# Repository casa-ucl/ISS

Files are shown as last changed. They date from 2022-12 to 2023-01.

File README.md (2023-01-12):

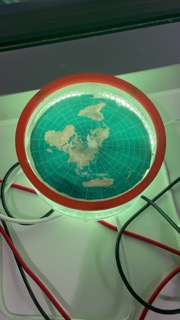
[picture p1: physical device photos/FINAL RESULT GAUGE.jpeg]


# ISS-Tracker-Overview

Welcome to our International Space Station (ISS) Tracking Device project! This project is a physical gauge that displays the position and visibility of the ISS in real-time using a combination of a rotating map, LED lights, and a servo motor. The device was developed by a team of students and is powered by an Arduino NodeMCU board.

This GitHub repository contains all the files and information related to the project, including:

The code for the NodeMCU and the augmented reality app
3D model files for the physical device and the animation created in Blender
Photos and instructions for 3D printing the device
The project report and bibliography
Collaboration folder that contains information on the team members' individual contributions and their roles on the project
To access and use the files, please navigate through the different folders and open the files in the appropriate software.
If you have any questions or feedback, please do not hesitate to contact us. Thank you for visiting our repository and we hope you enjoy our project.

# Introduction

First launched in 1998, The International Space Station (ISS) is the Earth’s biggest artificial satellite and the largest spacecraft ever constructed. It is the world’s only microgravity science lab where researchers conduct experiments across a wide variety of disciplines, often with groundbreaking results (NASA, 2020).  Its unique research environment and level of international cooperation required for its running make the ISS  “the most complex engineering, scientific, collaborative human feat ever managed” (NASA, 2020). Orbiting about 400 kilometers above Earth, it travels 28,000km/h and makes a complete orbits every 90 minutes, or 16 times per day. The ISS reflects sunlight and can be seen with the naked eye as a bright white pinpoint of light in the sky moving at a constant speed (NASA, 2013). Spotting the ISS is a popular hobby, and is regarded as one of the most intriguing and rewarding stargazing activities (Beall, 2023). For that reason, there are many apps and websites dedicated to mapping the live location of the ISS, such as AstroViewer (AstroViewer, 2022), NASA’s Spot the Station (Spot The Station, 2020), and mobile applications GoISSWatch ISS Tracking (GoSoftWorks, 2021), and ISS Finder (Harry Slotwiner, 2022). Following this trend, our team thought it would be fulfilling to create a physical device that tracked the location of this iconic spacecraft.

# Workspace
* 3D printer (Original Prusa i3 MK3S or MK3S+)
* Fusion 360 for 3D modeling
* [Blender for animation](https://www.youtube.com/watch?v=Yl_qDDRlXHo)
* Unity for AR development and Google Pixel 4a as the target platform
* Servo motors, LEDs, and acrylic sheets to construct the physical device
* Arduino IDE and C# for programming

# physical divice component
- Servo motors
- LEDs
- Acrylic sheets
- Arduino NodeMCU
- 360 Lego Geekservo
- Adafruit Neopixel Stick
- WS2812B LED Strip
- Globe map

# For the Arduino code:
- Remeber to change the WiFi credentials to the WiFi you want to connect to.
- When it starts, expect the LED strip (visibility) to turn on white.
- Expect all the LEDs on the NeoPixel board (latitude) to turn on red.
- Expect the servo (longitude) to turn to the 0 degrees location.
- Move the map so that the 0 degrees latitude line is aligned to the led line formed by the latitude LEDs.
- The device will automatically make a request to the API and once it recives a response the lights and servo will then update automatically every 5 seconds to the correct positions.

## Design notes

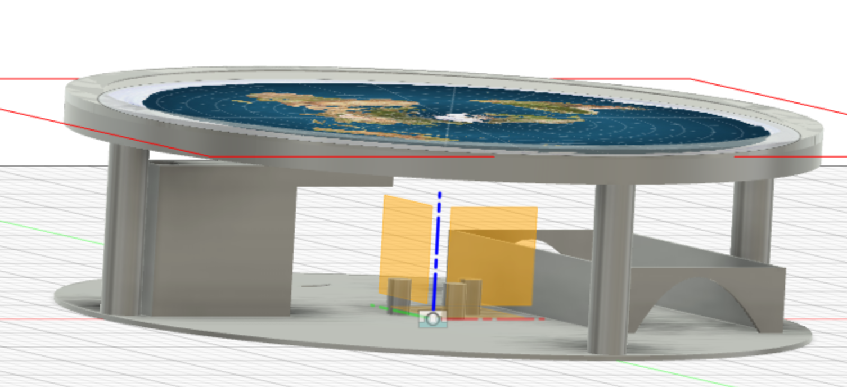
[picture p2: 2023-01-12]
physical device photos/into the gauge fusion 360.png

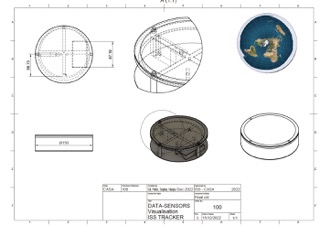
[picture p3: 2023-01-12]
physical device photos/drawing screen shot Small.jpeg

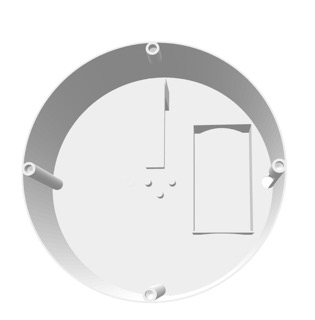
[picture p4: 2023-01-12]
physical device photos/Gaugebase Small.jpeg

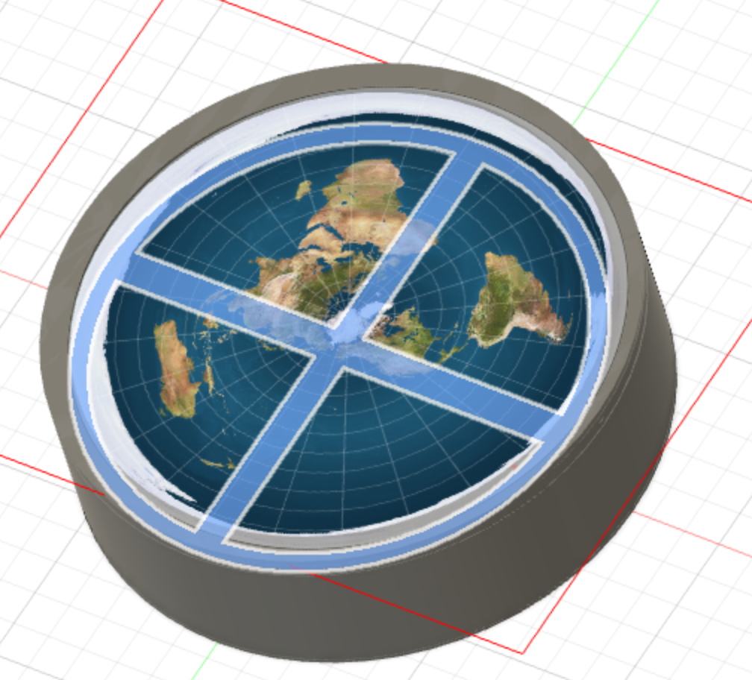
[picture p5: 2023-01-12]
physical device photos/map holder .png

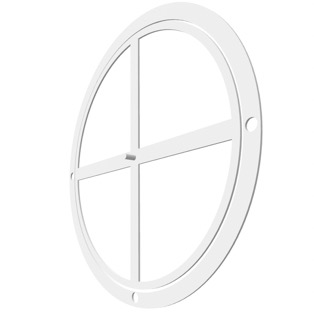
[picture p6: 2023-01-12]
physical device photos/Mapholder(wheel) Small.jpeg

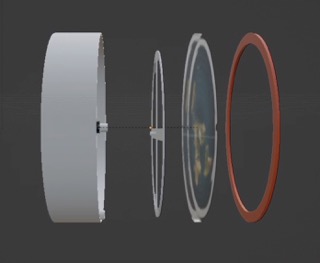
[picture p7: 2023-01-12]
physical device photos/Blender exploded Small.jpeg

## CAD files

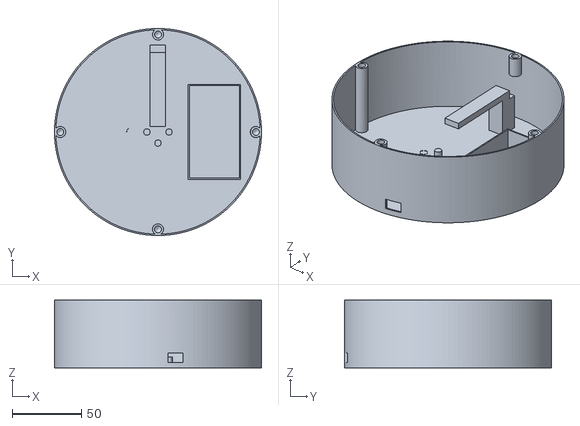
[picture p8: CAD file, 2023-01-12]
ISS Designing (all type of files)/UNity version v1 v7.stl
150.0 x 150.0 x 49.0

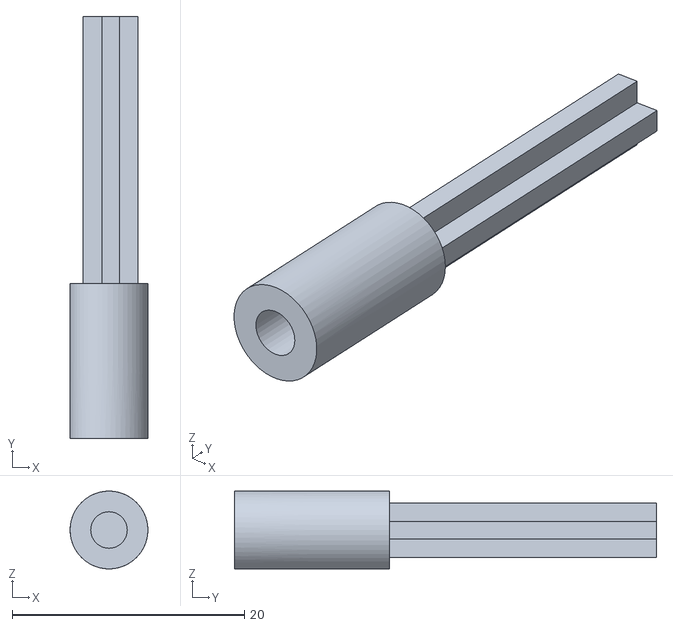
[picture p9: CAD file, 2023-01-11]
ISS Designing (all type of files)/LegoConnector.stl
6.70 x 36.3 x 6.70

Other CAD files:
ISS Designing (all type of files)/UNity version.f3d

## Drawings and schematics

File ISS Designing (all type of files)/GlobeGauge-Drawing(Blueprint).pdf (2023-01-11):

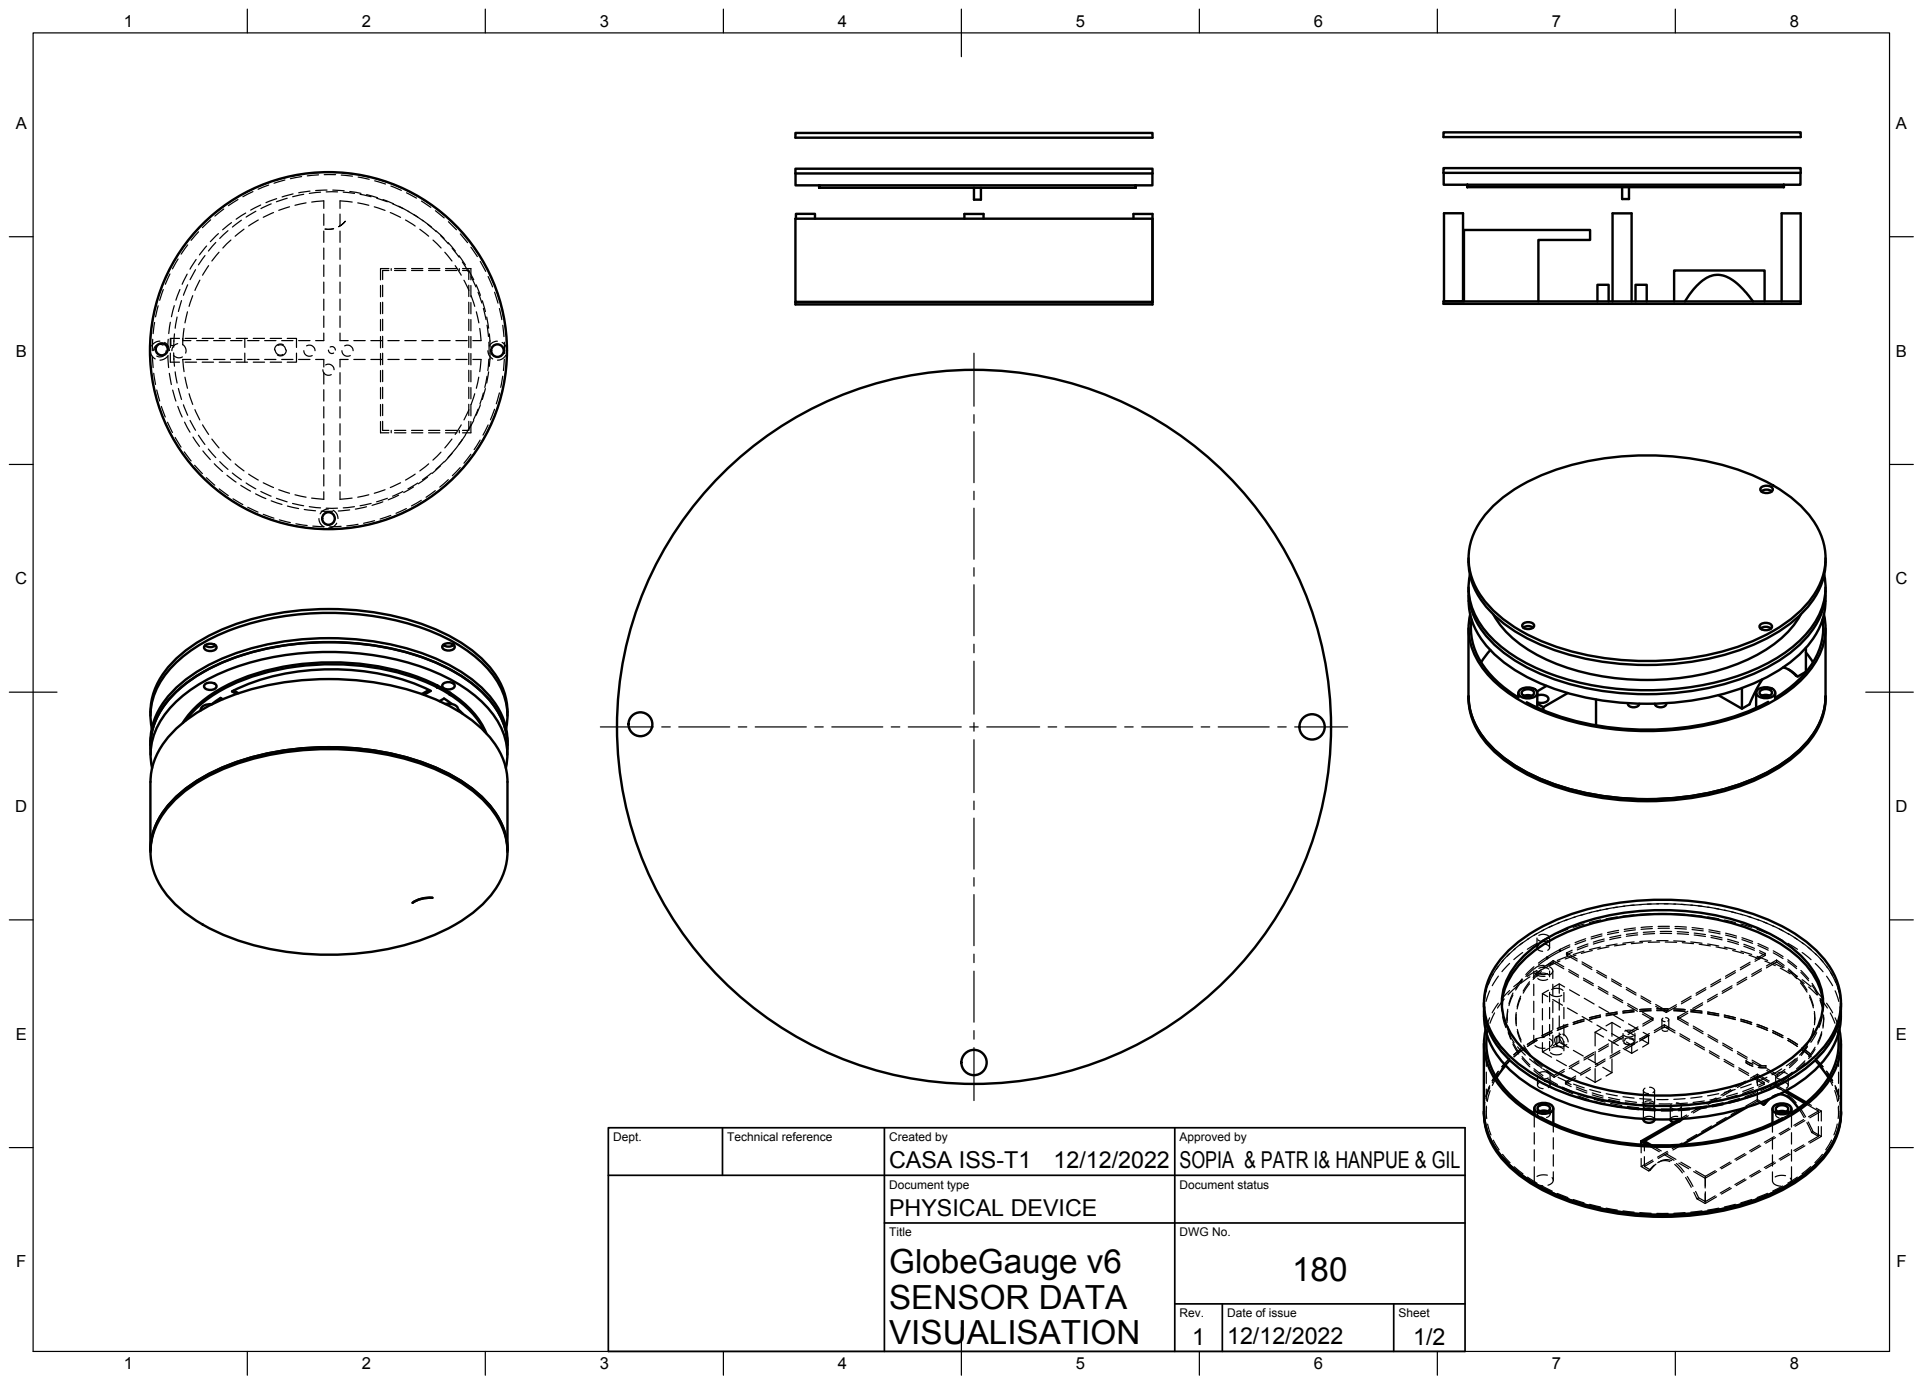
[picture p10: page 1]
Title; DWG No.; Rev.; Date of issue; Sheet; SENSOR DATA; GlobeGauge v6

Dept. | Technical reference | Created by CASA ISS-T1 12/12/2022 | Approved by SOPIA & PATR I& HANPUE & GIL

Document type PHYSICAL DEVICE | Document status

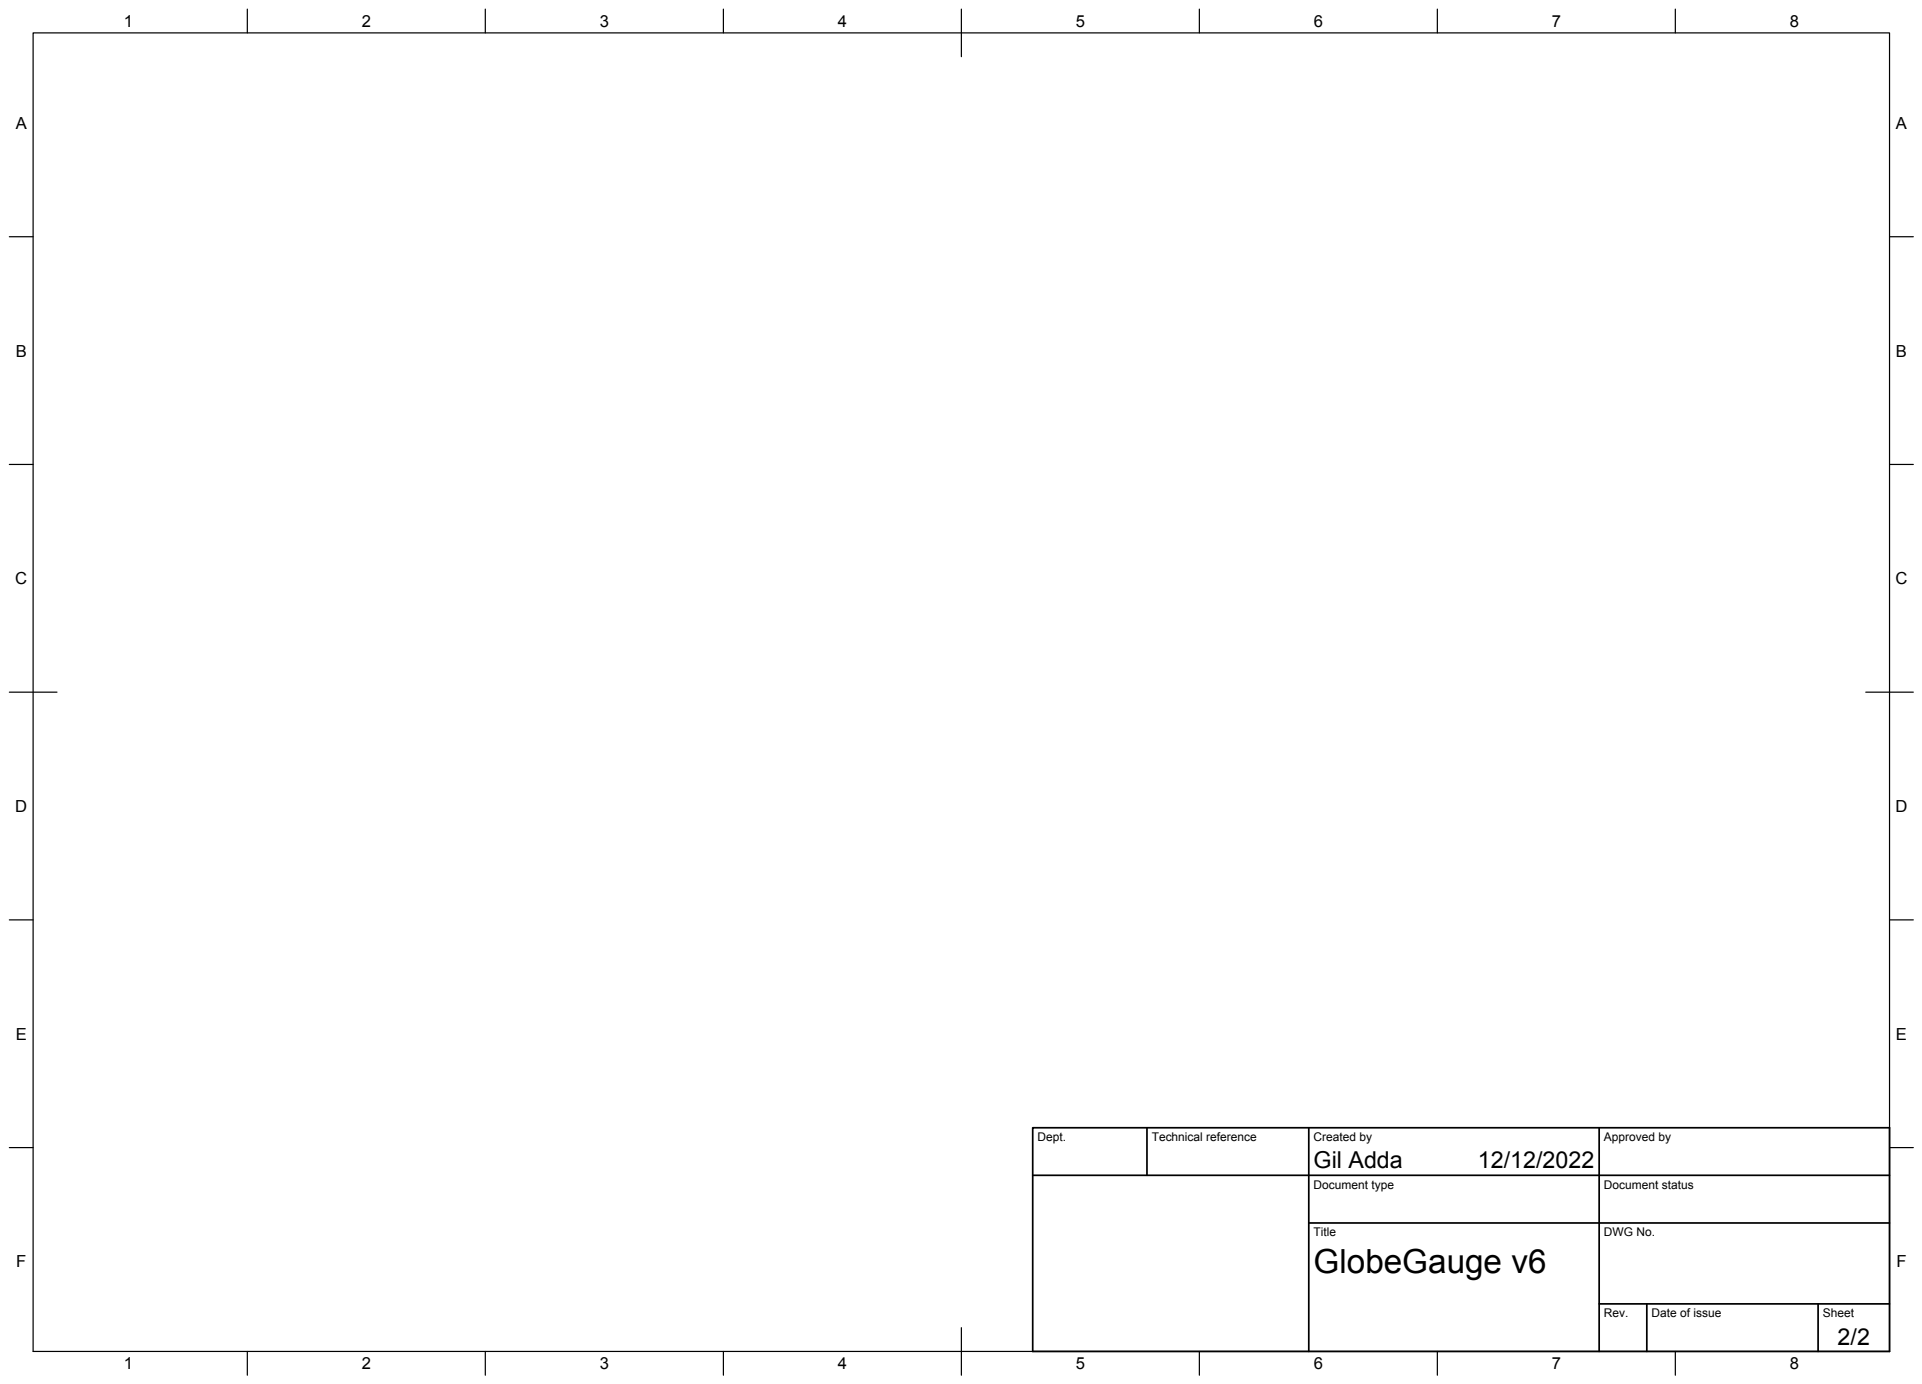
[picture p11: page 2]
Title; DWG No.; Rev.; Date of issue; Sheet; GlobeGauge v6

Dept. | Technical reference | Created by Gil Adda 12/12/2022 | Approved by

Document type | Document status

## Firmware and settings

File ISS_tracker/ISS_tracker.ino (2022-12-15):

/*
 * CASA0019 Group Project - ISS Tracker
 * Group 1 Astronaut - Gil Adda, Patrick Whyte, Sophia Chong, Hanpu Liu
 *
 * Using:
 * HTTPS Secured Client GET Request
 * Copyright (c) 2019, circuits4you.com
 * All rights reserved.
 * https://circuits4you.com 
 */

#include <ESP8266WiFi.h>
#include <WiFiClientSecure.h> 
#include <ESP8266WebServer.h>
#include <ESP8266HTTPClient.h>
#include <ArduinoJson.h>

#include <Servo.h>
#include <Adafruit_NeoPixel.h>

#define LAT_LED_PIN 12 // PIN D6 on NodeMCU
#define LAT_NUM_PIXELS 8

#define VIS_LED_PIN 14 // PIN D5 on NodeMCU
#define VIS_NUM_PIXELS 100

#define LON_SER_PIN 13 // PIN D7 on NodeMCU

/* Set these to your desired credentials. */
const char *ssid = "CE-Hub-Student";  //ENTER YOUR WIFI SETTINGS
const char *password = "casa-ce-gagarin-public-service";

//Web/Server address to read/write from 
const char *host = "api.wheretheiss.at";
const int httpsPort = 443;  //HTTPS= 443 and HTTP = 80

//SHA1 finger print of certificate use web browser to view and copy
const char fingerprint[] PROGMEM = "D5 28 75 E9 DB C8 8C 13 7A 9E 2B 04 B0 09 C3 D8 DE 7B 6E FB";

//API variables
int latitude;
int longitude;
String visibility;

//JSON document
DynamicJsonDocument doc(2048);

// Geekservo (longitude)
Servo servo;

// Initialize NeoPixel 8 Board (latitude)
Adafruit_NeoPixel pixels(LAT_NUM_PIXELS, LAT_LED_PIN);
// Initialize NeoPixel Strip (visibility)
Adafruit_NeoPixel strip(VIS_NUM_PIXELS, VIS_LED_PIN,  NEO_RGB + NEO_KHZ800);

void setup() {
  delay(1000);
  Serial.begin(115200);

  // Servo Code
  servo.attach(LON_SER_PIN);
  servo.write(0);

  // start NeoPixel board LEDs and set them all to be red to initalize
  pixels.begin();
  for (int i = 0; i < LAT_NUM_PIXELS; i++){
    pixels.setPixelColor(i, 200, 0, 0);
    pixels.show();
  }

  // Start Strip LEDs and set them to be white to initalize
  strip.begin();
  for (int i = 0; i < VIS_NUM_PIXELS; i++){
      strip.setPixelColor(i, 200, 200, 200);
      strip.show();
    }

  //start of wifi code TODO: move bloc to own function
  WiFi.mode(WIFI_OFF);        //Prevents reconnection issue (taking too long to connect)
  delay(1000);
  WiFi.mode(WIFI_STA);        //Only Station No AP, This line hides the viewing of ESP as wifi hotspot
  
  WiFi.begin(ssid, password);     //Connect to your WiFi router
  Serial.println("");

  Serial.print("Connecting");
  // Wait for connection
  while (WiFi.status() != WL_CONNECTED) {
    delay(500);
    Serial.print(".");
  }

  //If connection successful show IP address in serial monitor
  Serial.println("");
  Serial.print("Connected to ");
  Serial.println(ssid);
  Serial.print("IP address: ");
  Serial.println(WiFi.localIP());
}

void loop() {
  WiFiClientSecure httpsClient;

  Serial.println(host);

  Serial.printf("Using fingerprint '%s'\n", fingerprint);
  httpsClient.setFingerprint(fingerprint);
  httpsClient.setTimeout(15000); // 15 Seconds
  delay(1000);
  
  Serial.print("HTTPS Connecting");
  int r=0; //retry counter
  while((!httpsClient.connect(host, httpsPort)) && (r < 30)){
      delay(100);
      Serial.print(".");
      r++;
  }
  if(r==30) {
    Serial.println("Connection failed");
  }
  else {
    Serial.println("Connected to web");
  }
  
  //Declare holding variables
  String getData, Link;

  //GET Data
  Link = "/v1/satellites/25544";

  Serial.print("requesting URL: ");
  Serial.println(host+Link);

  httpsClient.print(String("GET ") + Link + " HTTP/1.1\r\n" +
               "Host: " + host + "\r\n" +               
               "Connection: close\r\n\r\n");

  Serial.println("request sent");
                  
  while (httpsClient.connected()) {
    String line = httpsClient.readStringUntil('\n');
    if (line == "\r") {
      Serial.println("headers received");
      break;
    }
  }

  Serial.println("reply was:");
  Serial.println("==========");
  String response;
  while(httpsClient.available()){        
    response = httpsClient.readStringUntil('\n');  //Read response
    Serial.println(response); //Print response
  }
  Serial.println("==========");
  Serial.println("closing connection");

  //Parse JSON, read error if any
  DeserializationError error = deserializeJson(doc, response);
  if(error) {
     Serial.print(F("deserializeJson() failed: "));
     Serial.println(error.f_str());
     delay(5000);
     return;
  }

  // Update values from the response from the API
  latitude = doc["latitude"].as<int>();
  Serial.print("Latitude: ");
  Serial.println(latitude);

  longitude = doc["longitude"].as<int>();
  Serial.print("Longitude: ");
  Serial.println(longitude);

  visibility = doc["visibility"].as<String>();
  Serial.print("Visibility: ");
  Serial.println(visibility);

  // Update the hardware to show changes from the API  
  updateLongitude();
  updateLatitude();
  updateVisibility();  
    
  delay(5000);  //GET Data at every 2 seconds
}

// Helper Methods
void updateLongitude() {
int mappedLongitude = map(longitude, -180, 180, 360, 0);
servo.write(mappedLongitude);
}

void updateVisibility() {
  if (visibility == "daylight") {
    for (int i = 0; i < VIS_NUM_PIXELS; i++){
      strip.setPixelColor(i, 252, 223, 3); // orange
      strip.show();
    }
  } else {  // "eclipsed" the ISS is in shadow
    for (int i = 0; i < VIS_NUM_PIXELS; i++){
      strip.setPixelColor(i, 107, 3, 252); // purple
      strip.show();
    }
  }
}

void updateLatitude() {
  //reset all the LEDs so only one is showing at a time
  for (int i = 0; i < LAT_NUM_PIXELS; i++){
    pixels.setPixelColor(i, 0, 0, 0);
    pixels.show();
  }
  //use the map function to remap the latitude to a number between 0-7 
  //then light up that LED
  //update: since I resoldered the Neopixel LED the opposite way, remap to 7-0 instead
  //int ledToLight = map(latitude, -90, 90, 0, 7);
  int ledToLight = map(latitude, -90, 90, 7, 0);
  pixels.setPixelColor(ledToLight, 100, 0, 0);
  pixels.show();
}

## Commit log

2022-12-03 WIP Arduino NodeMCU code
2022-12-04 Arduino NodeMCU code to connect to API using HTTPS protocol
2022-12-04 Adds JSON parsing to arduino code
2022-12-08 Update README.md to include arduino instructions
2022-12-08 Update ISS_tracker.ino
    Since I resoldered the Neopixel LED on the opposite end, we remap the values from 7-0 instead
2022-12-12 Fixes number of pixels used for neopixel board
    [ISS_tracker.ino]
2022-12-14 Changes servo code to work with negative longitude lines
2022-12-14 Changes code to use correct reference to LEDs
    [ISS_tracker.ino]
2022-12-14 changes so LED for latitude is on at start up
